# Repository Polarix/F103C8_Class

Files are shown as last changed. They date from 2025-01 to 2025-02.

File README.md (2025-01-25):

# STM32F103C8单片机核心板
这是一款设计用于STM32F103C8T6单片机及引脚布局兼容单片机的核心板设计。

原理图和PCB设计使用KiCAD完成，依赖以下符号库和封装库。
 - [kicad_libs_append](https://github.com/Polarix/kicad_libs_append)

## 设计目标
电路设计尝试兼容以下芯片及其引脚兼容型号：

|型号|封装|特征及其改动|
|-|-|-|
|STM32F103C8T6|LQFP-48|以此为基础型号。|
|STM32F030C8T6|LQFP-48|取消一组电源，35、36两个引脚增加PF6、PF7两个GPIO，可复用为USART3的TX、RX两个引脚以及TIM16和TIM17的1通道。|
|STM32F401CCU6|QFN-48|34脚改为VCAP，用作内部电压调节器滤波，并取消了PB11引脚，USART3不可用并被替换为了USART6。|

## 预览图
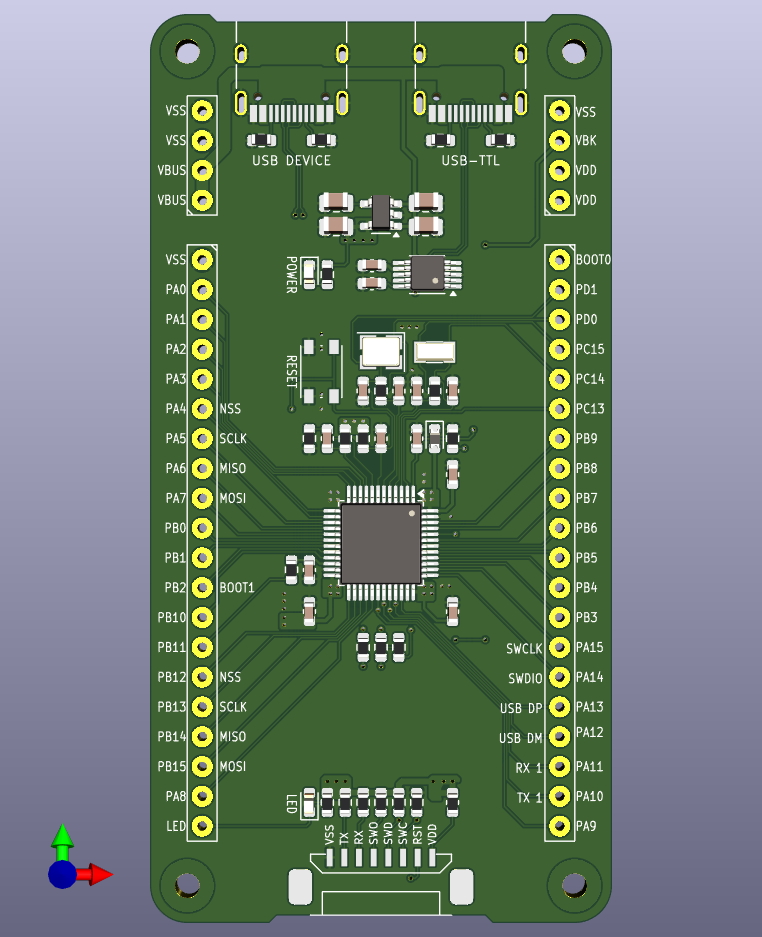
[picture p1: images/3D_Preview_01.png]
KiCAD 3D预览 3D预览1

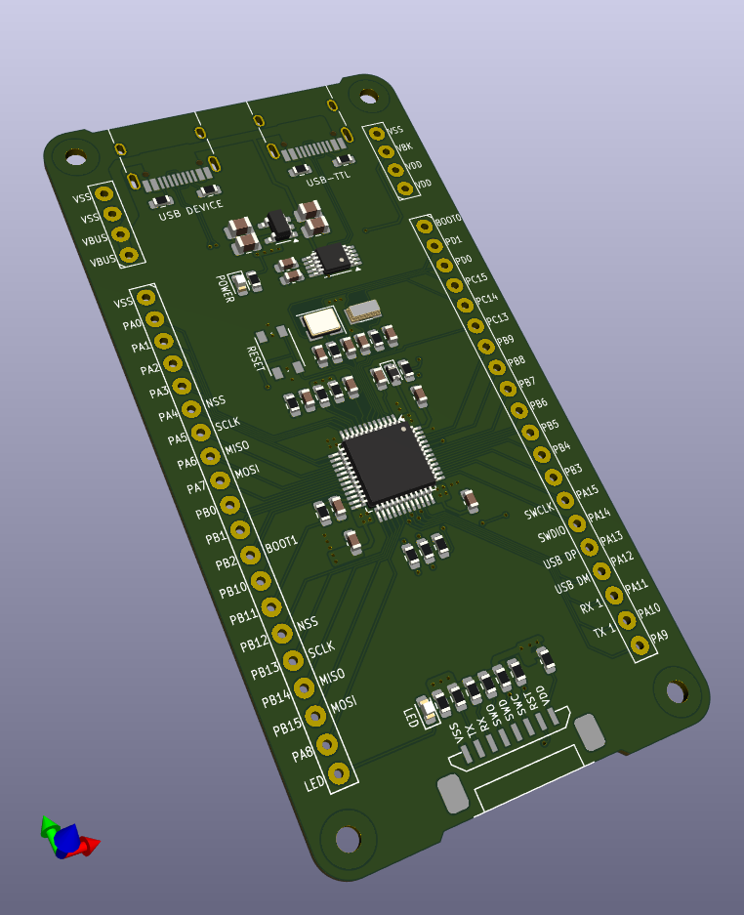
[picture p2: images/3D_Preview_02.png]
KiCAD 3D预览 3D预览2


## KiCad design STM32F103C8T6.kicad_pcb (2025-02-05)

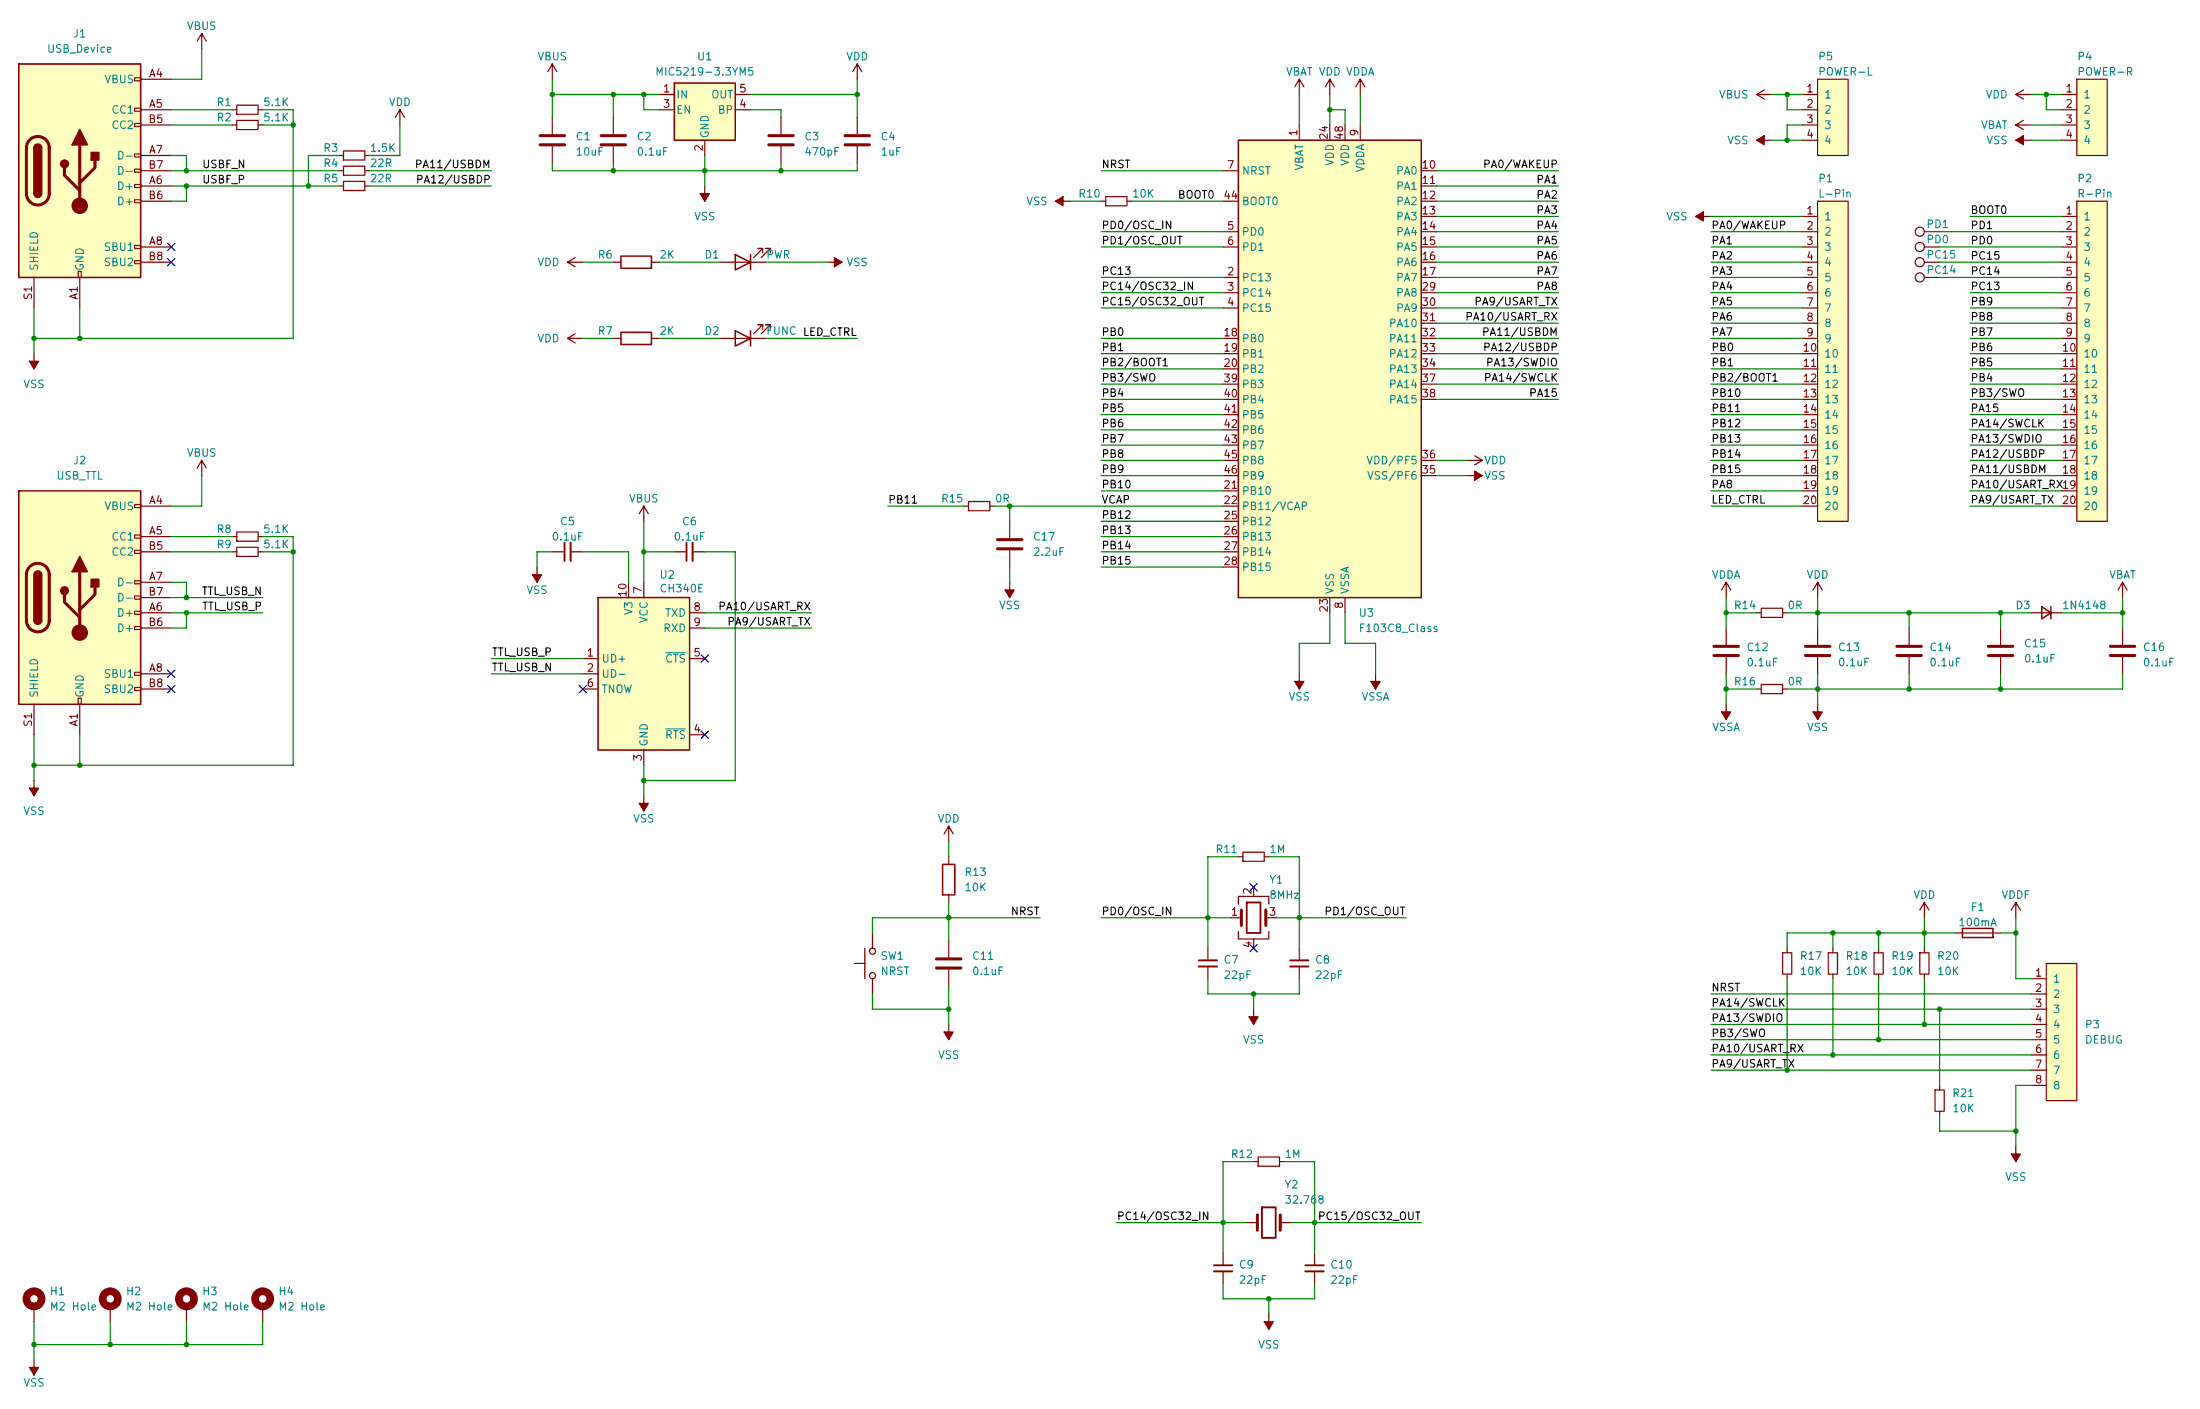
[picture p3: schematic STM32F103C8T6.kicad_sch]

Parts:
C1: 10uF; C_0805_2012Metric
C2: 0.1uF; C_0805_2012Metric
C3: 470pF; C_0805_2012Metric
C4: 1uF; C_0805_2012Metric
C5, C6, C11, C12, C13, C14, C15, C16: 0.1uF; C_0603_1608Metric
C7, C8, C9, C10: 22pF; C_0603_1608Metric
C17: 2.2uF; C_0603_1608Metric
D1: PWR; LED_0603_1608Metric
D2: FUNC; LED_0603_1608Metric
D3: 1N4148; D_0603_1608Metric
F1: 100mA; Fuse_0603_1608Metric
H1, H2, H3, H4: M2 Hole; Hole_2×4.5mm
J1: USB_Device; USB_C_Receptacle_HRO_TYPE-C-31-M-12
J2: USB_TTL; USB_C_Receptacle_HRO_TYPE-C-31-M-12
P1: L-Pin; HDR1×20_2.54mm
P2: R-Pin; HDR1×20_2.54mm
P3: DEBUG; JST1.25mm_8P_SMD_Horizontal
P4: POWER-R; HDR1×4_2.54mm
P5: POWER-L; HDR1×4_2.54mm
R1, R2, R8, R9: 5.1K; R_0603_1608Metric
R3: 1.5K; R_0603_1608Metric
R4, R5: 22R; R_0603_1608Metric
R6, R7: 2K; R_0603_1608Metric
R10, R13, R17, R18, R19, R20, R21: 10K; R_0603_1608Metric
R11, R12: 1M; R_0603_1608Metric
R14, R15, R16: 0R; R_0603_1608Metric
SW1: NRST; TS-1070
TP1: PD1; PAD_Semicircular_1mm
TP2: PD0; PAD_Semicircular_1mm
TP3: PC15; PAD_Semicircular_1mm
TP4: PC14; PAD_Semicircular_1mm
U1: MIC5219-3.3YM5; SOT-23-5
U2: CH340E; MSOP-10_3x3mm_P0.5mm
U3: F103C8_Class; LQFP-48_7x7mm_P0.5mm
Y1: 8MHz; Crystal_SMD_3225-4Pin_3.2x2.5mm
Y2: 32.768; Crystal_SMD_3215-2Pin_3.2x1.5mm

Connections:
/BOOT0: P2.1, R10.2, U3.44 (BOOT0)
/LED_CTRL: D2.1 (K), P1.20
/NRST: C11.1, P3.2, R13.2, SW1.2, U3.7 (NRST)
/PA0/WAKEUP: P1.2, U3.10 (PA0)
/PA1: P1.3, U3.11 (PA1)
/PA2: P1.4, U3.12 (PA2)
/PA3: P1.5, U3.13 (PA3)
/PA4: P1.6, U3.14 (PA4)
/PA5: P1.7, U3.15 (PA5)
/PA6: P1.8, U3.16 (PA6)
/PA7: P1.9, U3.17 (PA7)
/PA8: P1.19, U3.29 (PA8)
/PA9/USART_TX: P2.20, P3.7, R17.2, U2.9 (RXD), U3.30 (PA9)
/PA10/USART_RX: P2.19, P3.6, R18.2, U2.8 (TXD), U3.31 (PA10)
/PA11/USBDM: P2.18, R4.2, U3.32 (PA11)
/PA12/USBDP: P2.17, R5.2, U3.33 (PA12)
/PA13/SWDIO: P2.16, P3.4, R20.2, U3.34 (PA13)
/PA14/SWCLK: P2.15, P3.3, R21.1, U3.37 (PA14)
/PA15: P2.14, U3.38 (PA15)
/PB0: P1.10, U3.18 (PB0)
/PB1: P1.11, U3.19 (PB1)
/PB2/BOOT1: P1.12, U3.20 (PB2)
/PB3/SWO: P2.13, P3.5, R19.2, U3.39 (PB3)
/PB4: P2.12, U3.40 (PB4)
/PB5: P2.11, U3.41 (PB5)
/PB6: P2.10, U3.42 (PB6)
/PB7: P2.9, U3.43 (PB7)
/PB8: P2.8, U3.45 (PB8)
/PB9: P2.7, U3.46 (PB9)
/PB10: P1.13, U3.21 (PB10)
/PB11: P1.14, R15.1
/PB12: P1.15, U3.25 (PB12)
/PB13: P1.16, U3.26 (PB13)
/PB14: P1.17, U3.27 (PB14)
/PB15: P1.18, U3.28 (PB15)
/PC13: P2.6, U3.2 (PC13)
/PC14: P2.5, TP4.1
/PC14/OSC32_IN: C9.1, R12.1, U3.3 (PC14), Y2.1
/PC15: P2.4, TP3.1
/PC15/OSC32_OUT: C10.1, R12.2, U3.4 (PC15), Y2.2
/PD0: P2.3, TP2.1
/PD0/OSC_IN: C7.1, R11.1, U3.5 (PD0), Y1.1
/PD1: P2.2, TP1.1
/PD1/OSC_OUT: C8.1, R11.2, U3.6 (PD1), Y1.3
/TTL_USB_N: J2.A7 (D-), J2.B7 (D-), U2.2 (UD-)
/TTL_USB_P: J2.A6 (D+), J2.B6 (D+), U2.1 (UD+)
/USBF_N: J1.A7 (D-), J1.B7 (D-), R4.1
/USBF_P: J1.A6 (D+), J1.B6 (D+), R3.1, R5.1
/VCAP: C17.2, R15.2, U3.22 (PB11/VCAP)
unnamed: D1.2 (A), R6.2
unnamed: D2.2 (A), R7.2
unnamed: J1.A5 (CC1), R1.1
unnamed: J1.B5 (CC2), R2.1
unnamed: J2.A5 (CC1), R8.1
unnamed: J2.B5 (CC2), R9.1
unnamed: C3.1, U1.4 (BP)
unnamed: C5.2, U2.10 (V3)
VBAT: C16.1, D3.1 (K), P4.3, U3.1 (VBAT)
VBUS: C1.1, C2.1, C6.1, J1.A4 (VBUS), J1.A9 (VBUS), J1.B4 (VBUS), J1.B9 (VBUS), J2.A4 (VBUS), J2.A9 (VBUS), J2.B4 (VBUS), J2.B9 (VBUS), P5.1, P5.2, U1.1 (IN), U1.3 (EN), U2.7 (VCC)
VDD: C4.1, C13.1, C14.1, C15.1, D3.2 (A), F1.1, P4.1, P4.2, R3.2, R6.1, R7.1, R13.1, R14.2, R17.1, R18.1, R19.1, R20.1, U1.5 (OUT), U3.24 (VDD), U3.36 (VDD/PF5), U3.48 (VDD)
VDDA: C12.1, R14.1, U3.9 (VDDA)
VDDF: F1.2, P3.1
VSS: C1.2, C2.2, C3.2, C4.2, C5.1, C6.2, C7.2, C8.2, C9.2, C10.2, C11.2, C13.2, C14.2, C15.2, C16.2, C17.1, D1.1 (K), H1.MP, H2.MP, H3.MP, H4.MP, J1.A1 (GND), J1.A12 (GND), J1.B1 (GND), J1.B12 (GND), J1.S1 (SHIELD), J2.A1 (GND), J2.A12 (GND), J2.B1 (GND), J2.B12 (GND), J2.S1 (SHIELD), P1.1, P3.8, P4.4, P5.3, P5.4, R1.2, R2.2, R8.2, R9.2, R10.1, R16.2, R21.2, SW1.1, U1.2 (GND), U2.3 (GND), U3.23 (VSS), U3.35 (VSS/PF6), U3.47 (VSS), U3.49 (VSS)
VSSA: C12.2, R16.1, U3.8 (VSSA)

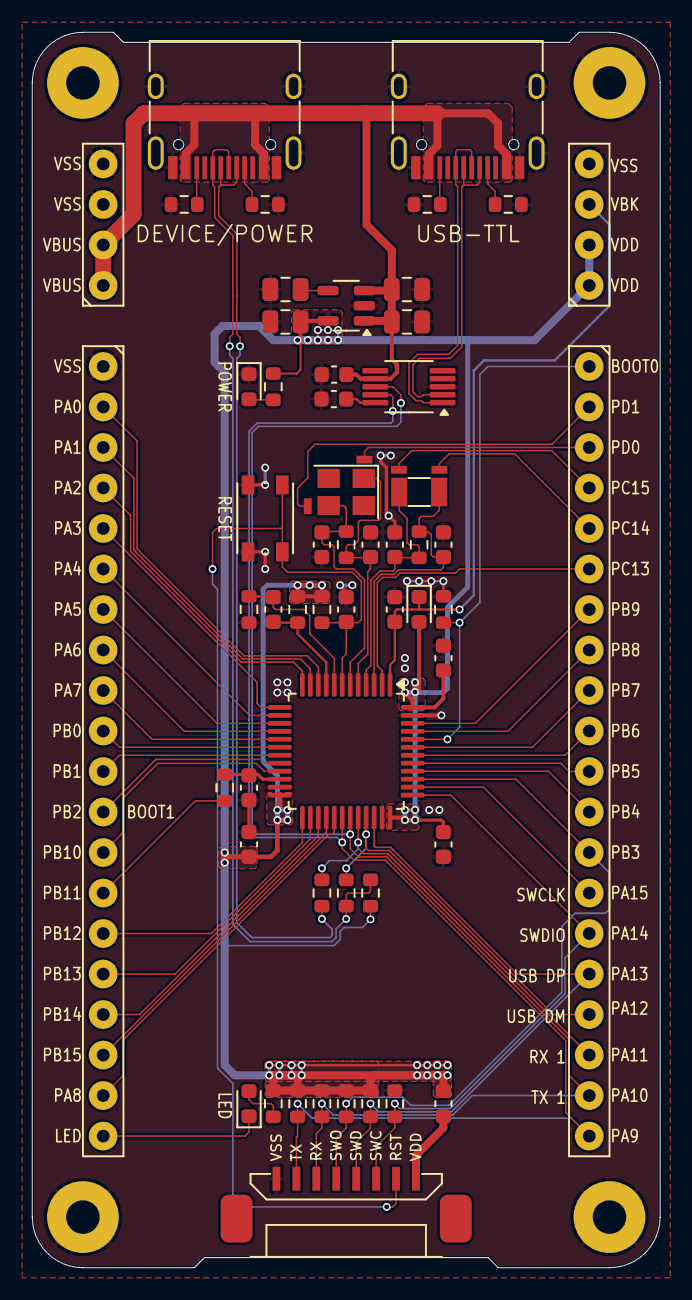
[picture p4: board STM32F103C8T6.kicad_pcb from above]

Board: 2 copper layers, 39.4 x 77.5 mm, 63 parts (0 on the bottom side), 64 nets.

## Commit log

2025-01-25 增加忽略规则文件
2025-01-25 增加针对自动备份路径的忽略规则
2025-01-25 增加初版KiCAD工程文件
    [STM32F103C8T6.kicad_pcb, STM32F103C8T6.kicad_sch]
2025-01-25 增肌Readme文件
2025-01-25 增加独立的电源连接端子
    [STM32F103C8T6.kicad_pcb, STM32F103C8T6.kicad_sch]
2025-01-25 修正晶振匹配电容铺地连接错误的问题
    [STM32F103C8T6.kicad_pcb]
2025-01-25 更新自述文件
2025-01-25 修正电器规则和布线错误
    [STM32F103C8T6.kicad_pcb]
2025-01-25 更新电路设计，兼容F401CC芯片
    [STM32F103C8T6.kicad_pcb, STM32F103C8T6.kicad_sch]
2025-01-25 更新描述文件
2025-01-25 优化电源走线
    [STM32F103C8T6.kicad_pcb, STM32F103C8T6.kicad_sch]
2025-01-25 更新说明文件，增加3D预览图
2025-01-25 更新Git忽略文件规则
2025-01-25 更新引脚链接，增加晶振引脚的跳接焊盘
    [STM32F103C8T6.kicad_pcb, STM32F103C8T6.kicad_sch]
2025-02-03 修改调试器接口的电源走线
    [STM32F103C8T6.kicad_pcb]
2025-02-05 修正了调试器接口的电源线宽度，底面增加了可以标注型号的留白
    [STM32F103C8T6.kicad_pcb]
